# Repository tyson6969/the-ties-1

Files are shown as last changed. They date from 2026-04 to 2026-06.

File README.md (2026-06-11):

# The Ties

A **9 key 3 encoder macropad** running on QMK firmware and a **RP2040 MCU**

**Features:**
- 3D printed shell
- Custom PCB
- LEDs
- All running on QMK firmware
- Change buttons, shortcuts, and LEDs from your browser on QMK
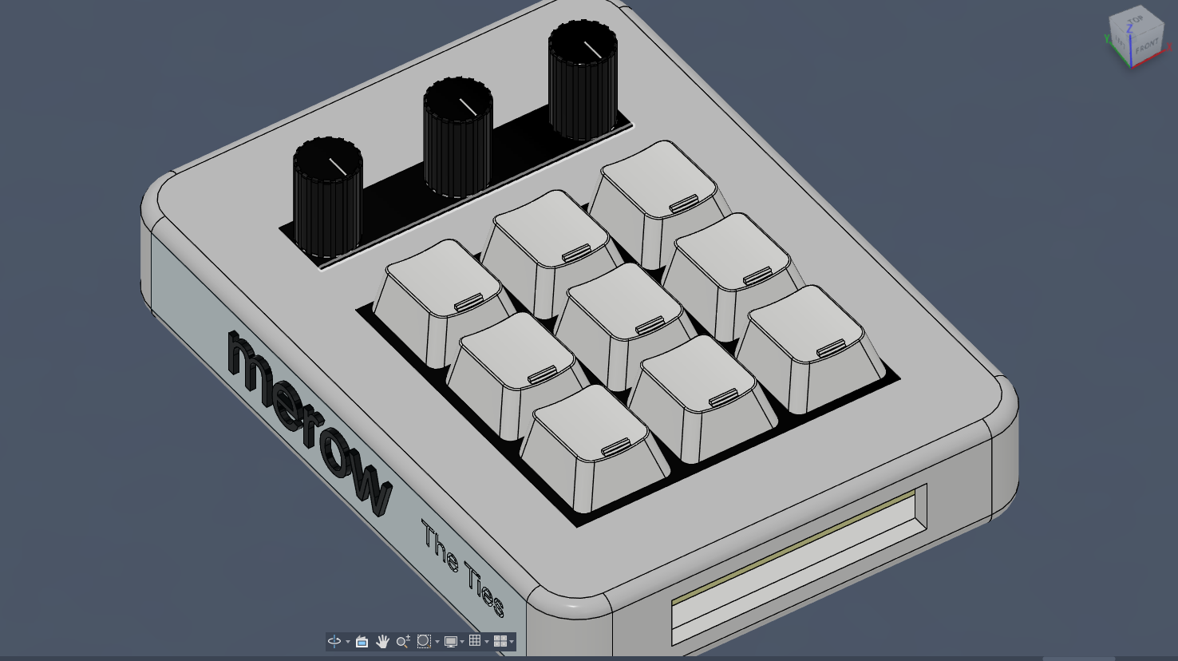
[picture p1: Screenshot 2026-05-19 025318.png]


## PCBA DESIGN

**A 4 layer board**

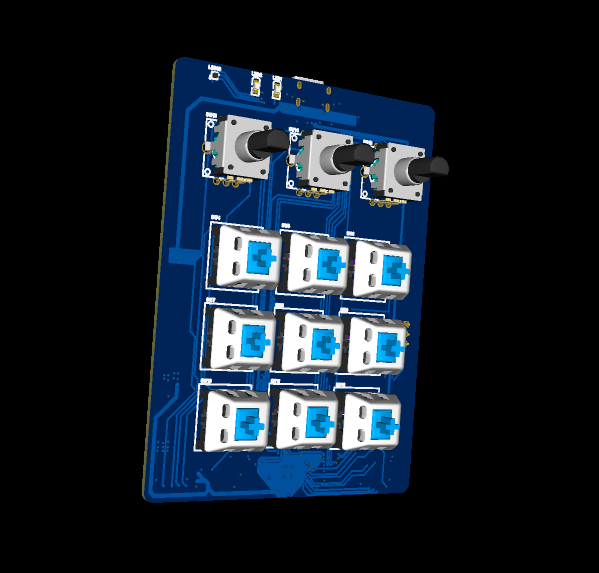
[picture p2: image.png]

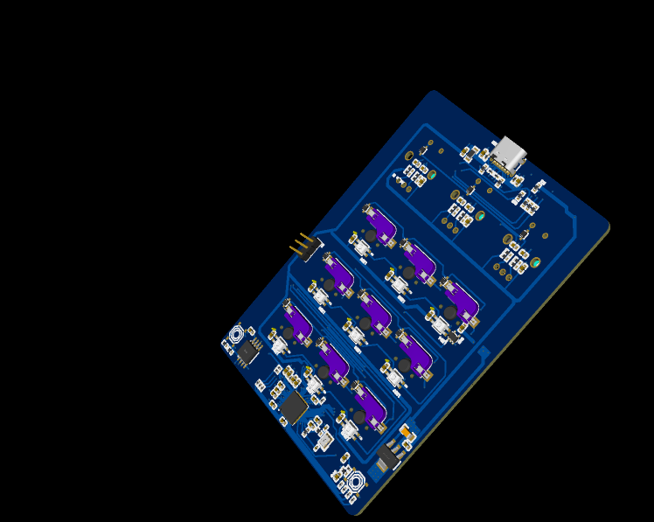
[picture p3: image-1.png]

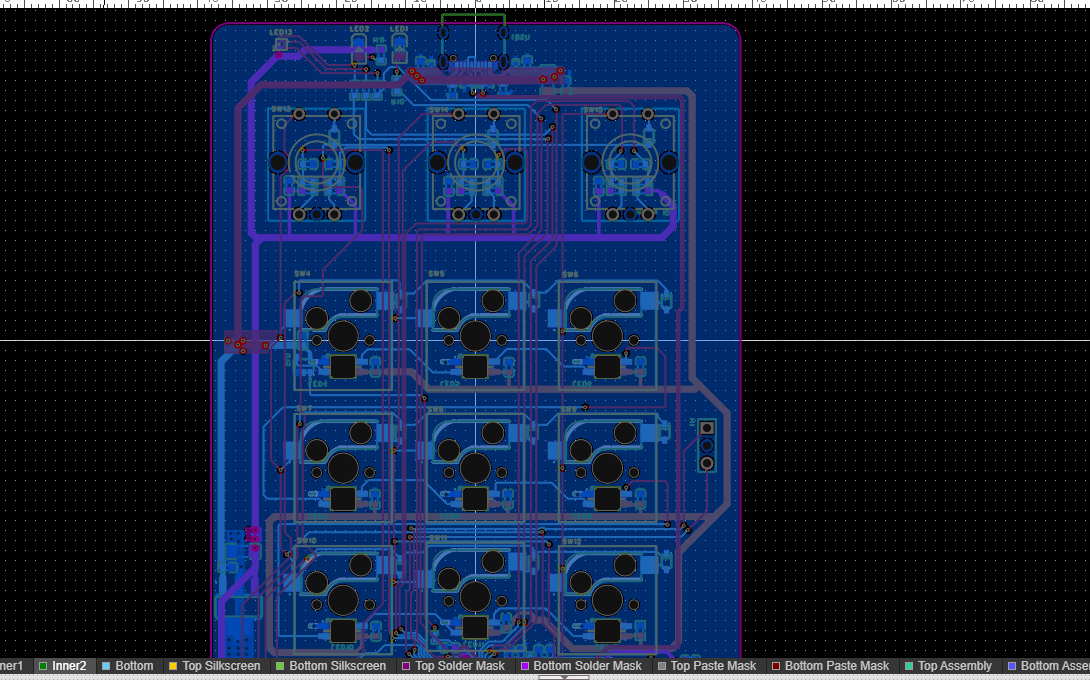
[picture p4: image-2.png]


Built on the **RP2040**  integrated directly into the board with all the typical components you will see on a RP2040 dev board.

**Schematics:**

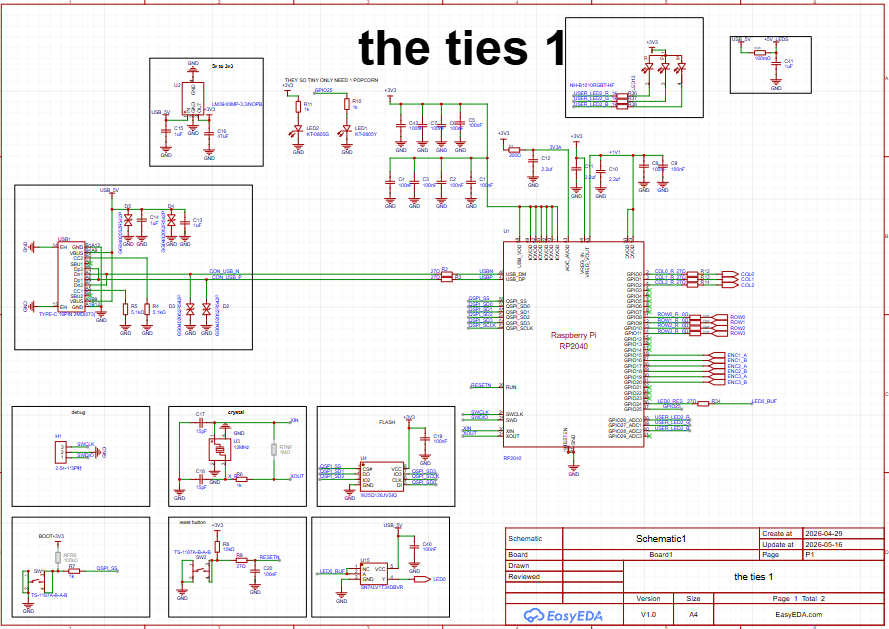
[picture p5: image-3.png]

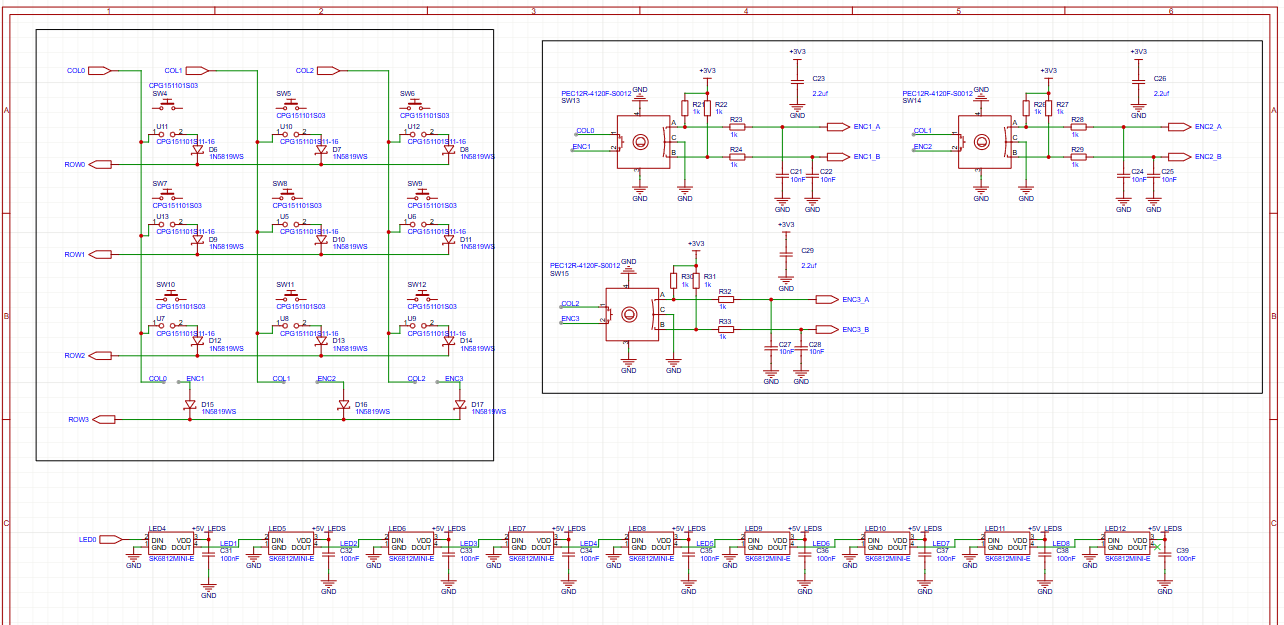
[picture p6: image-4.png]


## Case Design



Fully 3D printed

## Firmware

**Credits:**

This firmware is based on open source code by Robert Feranec
https://www.youtube.com/@RobertFeranec. 
i forked it with minimal modifications, but all the original code is from them.
It runs on **QMK firmware**, which is also open source.

## Files

### BOM
[BOM](https://github.com/tyson6969/the-ties-1/blob/main/BOM_Board1_Schematic1_2026-05-19.xlsx)

### Gerber Files
[Gerber Files](https://github.com/tyson6969/the-ties-1/blob/main/thetiesgerber.zip)

### 3D Printed Case
[3D Model](https://github.com/tyson6969/the-ties-1/blob/main/the%20ties%20CASE.stl)

### Software
[Software](https://github.com/tyson6969/the-ties-1/tree/main/Software)

### f3d files
[3D file ](https://github.com/tyson6969/the-ties-1/blob/main/the%20ties.f3z)

### ebro files
[3D file ](https://github.com/tyson6969/the-ties-1/blob/main/the%20ties%20.epro) this for mr cyao 

## Demo

https://youtu.be/uFGrd8xYUWo

# NO AI WAS USED IN THIS PROJECT

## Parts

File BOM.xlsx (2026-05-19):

No. | Quantity | Comment | Designator | Footprint | Value | Manufacturer Part | Manufacturer | Supplier Part | Supplier
1 | 22 | 100nF | C1,C2,C3,C4,C5,C6,C7,C8,C9,C19,C20,C31,C32,C33,C34,C35,C36,C37,C38,C39,C40,C42 | C0603 | 100nF
2 | 6 | 2.2uf | C10,C11,C12,C23,C26,C29 | C0603 | 2.2uf
3 | 4 | 1uF | C13,C14,C15,C41 | C0603 | 1uF
4 | 1 | 47uF | C16 | C1206 | 47uF | CL31A476MPHNNNE | SAMSUNG(三星) | C96123 | LCSC
5 | 2 | 15pF | C17,C18 | C0402 | 15pF | CL05C150JB5NNNC | SAMSUNG(三星) | C86285 | LCSC
6 | 6 | 10nF | C21,C22,C24,C25,C27,C28 | C0603 | 10nF
7 | 4 | GG0402052R542P | D2,D3,D4,D5 | D0402-BI |  | GG0402052R542P | Kyocera AVX | C1973257 | LCSC
8 | 12 | 1N5819WS | D6,D7,D8,D9,D10,D11,D12,D13,D14,D15,D16,D17 | SOD-323_L1.8-W1.3-LS2.5-RD |  | 1N5819WS | Hottech(合科泰) | C191023 | LCSC
9 | 1 | 2.54-1*3P针 | H1 | HDR-TH_3P-P2.54-V-M-1 |  | 2.54-1*3P针 | BOOMELE(博穆精密) | C49257 | LCSC
10 | 1 | KT-0805Y | LED1 | LED0805-R-RD |  | KT-0805Y | KENTO | C2296 | LCSC
11 | 1 | KT-0805G | LED2 | LED0805-R-RD |  | KT-0805G | KENTO | C2297 | LCSC
12 | 9 | SK6812MINI-E | LED4,LED5,LED6,LED7,LED8,LED9,LED10,LED11,LED12 | LED-SMD_4P-L3.2-W2.8-LS5.9_SK6812MINI-E |  | SK6812MINI-E | 欧思科光电 | C5149201 | LCSC
13 | 1 | NH-B1010RGBT-HF | LED13 | LED-ARRAY-SMD_4P-L1.0-W1.0-TR_NH-B1010RGBT |  | NH-B1010RGBT-HF | 国星光电 | C2874113 | LCSC
14 | 1 | 200Ω | R1 | R0402 | 200Ω | 0402WGF2000TCE | UNI-ROYAL(厚声) | C25087 | LCSC
15 | 7 | 27Ω | R2,R3,R9,R12,R13,R14,R34 | R0402 | 27Ω | 0402WGF270JTCE | UNI-ROYAL(厚声) | C25100 | LCSC
16 | 2 | 5.1kΩ | R4,R5 | R0603 | 5.1kΩ
17 | 19 | 1k | R6,R7,R10,R11,R21,R22,R23,R24,R26,R27,R28,R29,R30,R31,R32,R33,R36,R37,R38 | R0603 | 1k
18 | 1 | 10kΩ | R8 | R0603 | 10kΩ
19 | 4 | 0Ω | R18,R19,R20,R25 | R0402 | 0Ω | 0402WGF0000TCE | UNI-ROYAL(厚声) | C17168 | LCSC
20 | 1 | 100mΩ | R35 | R1206 | 100mΩ | 1206W4F100LT5E | UNI-ROYAL(厚声) | C25334 | LCSC
21 | 2 | TS-1187A-B-A-B | SW1,SW2 | SW-SMD_4P-L5.1-W5.1-P3.70-LS6.5-TL_H1.5 |  | TS-1187A-B-A-B | XKB Connection(中国星坤) | C318884 | LCSC
22 | 9 | CPG151101S03 | SW4,SW5,SW6,SW7,SW8,SW9,SW10,SW11,SW12 | KEY-TH_CPG1511F01S0X |  | CPG151101S03 | Kailh(凯华) | C404350 | LCSC
23 | 3 | PEC12R-4120F-S0012 | SW13,SW14,SW15 | SW-TH_PEC12R-4120F-S0012 |  | PEC12R-4120F-S0012 | BOURNS | C143801 | LCSC
24 | 1 | RP2040 | U1 | LQFN-56_L7.0-W7.0-P0.4-EP |  | RP2040 | Raspberry Pi(树莓派) | C2040 | LCSC
25 | 1 | LM3940IMP-3.3/NOPB | U2 | SOT-223_L6.5-W3.5-P2.30-LS7.0-BR |  | LM3940IMP-3.3/NOPB | TI(德州仪器) | C140319 | LCSC
26 | 1 | 12MHz | U3 | CRYSTAL-SMD_4P-L3.2-W2.5-BL | 12MHz | ABM8-272-T3 | ABRACON | C20625731 | LCSC
27 | 1 | W25Q128JVSIQ | U4 | SOIC-8_L5.3-W5.3-P1.27-LS8.0-BL |  | W25Q128JVSIQ | Winbond(华邦) | C97521 | LCSC
28 | 9 | CPG151101S11-16 | U5,U6,U7,U8,U9,U10,U11,U12,U13 | SMD_KEYBOARD-SW |  | CPG151101S11-16 | Kailh(凯华) | C5156480 | LCSC
29 | 1 | SN74LV1T34DBVR | U15 | SOT-23-5_L2.9-W1.6-P0.95-LS2.8-BR |  | SN74LV1T34DBVR | TI(德州仪器) | C100024 | LCSC
30 | 1 | TYPE-C 16PIN 2MD(073) | USB1 | USB-C-SMD_TYPE-C-16PIN-2MD-073 |  | TYPE-C 16PIN 2MD(073) | SHOU HAN(首韩) | C2765186 | LCSC

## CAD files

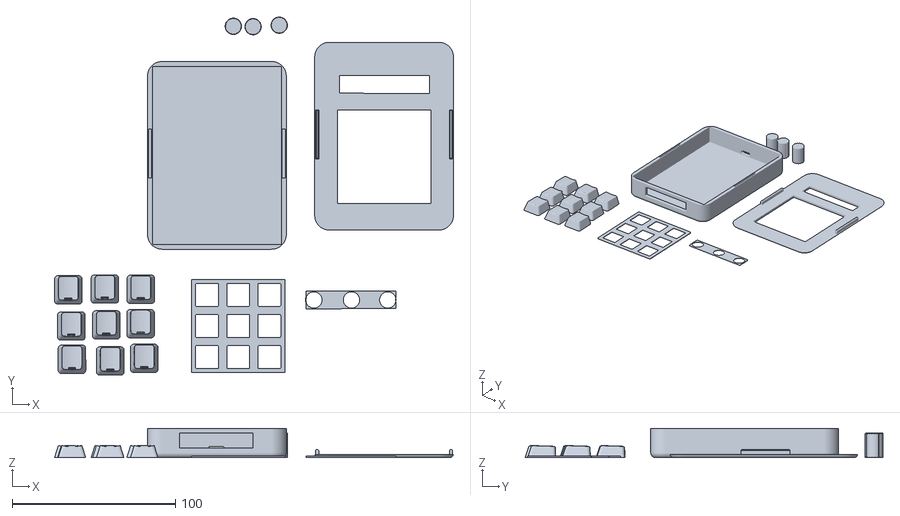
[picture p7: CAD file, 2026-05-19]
the ties CASE.stl
244.3 x 219.3 x 18.0

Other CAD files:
the ties.f3z

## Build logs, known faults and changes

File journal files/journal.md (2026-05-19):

sorry for the spelling mistakes i make 

day 1 the start 4/29/2026
time tracked - 1.30h

soooooooooooo firstly it was honestly annoying bro omg i wanted to make a macropad so i decided sure lemme make one how hard could it be i only used easyeda before and i dont feel like learning kicad so i just rolled with it i first had to see the qmk docs to know what i was dealing with then i chose a mcu i decided to go with the pico cus its easy yk lots of docs then i opened the docs for it went to the wiring diagram and hell began
i placed the chip in easyeda and i edited the footprint to make it look a lil nice easy to work with ik i am a dumbahh

so i started by adding all the capacitors linking them to gnd and honestly idk what was i doing i kept looking between the docs and drc to figure out what to do i added caps to the VODD pins all of em then i decided to add the usb c which gave me lots of trouble dude i first started routing it with my skills learnt from the usb hub hehehehe i connected them to the usb of the pico i added a shield but when i saw it it felt it looked ugly asf so i deleted everything and tried making it look pretty but i felt like it wont work so i had to redo everything again pain and now the usb c is done i think here is the schematics so far 
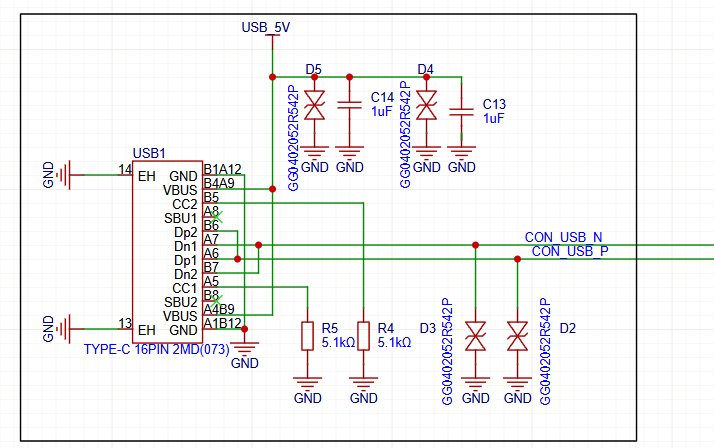
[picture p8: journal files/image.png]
looks so messy ik ik ! okay my dumbahh lost the pic sorry but here is the final usb c i think 

day 2 finished the mcu schematics 4/29/2026
time tracked - 1h

yippe i finished it i added a lot of things firstly the 
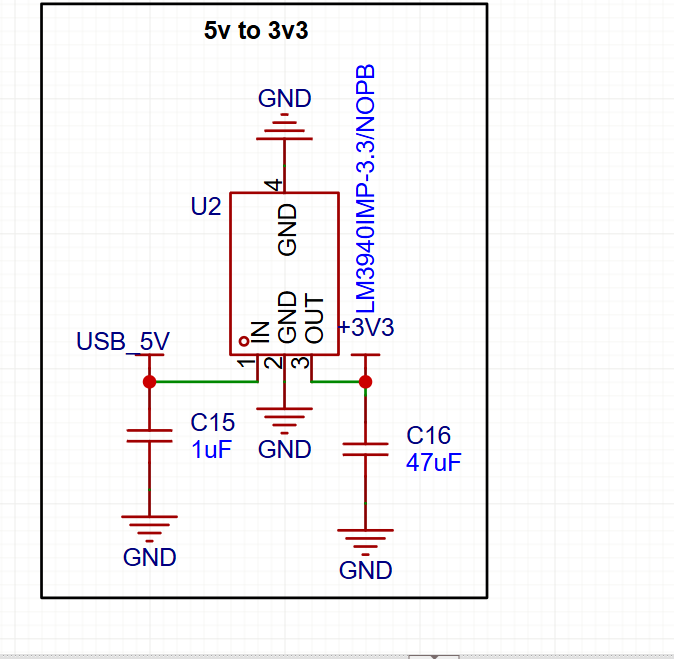
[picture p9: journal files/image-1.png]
voltage regulator 

crystal
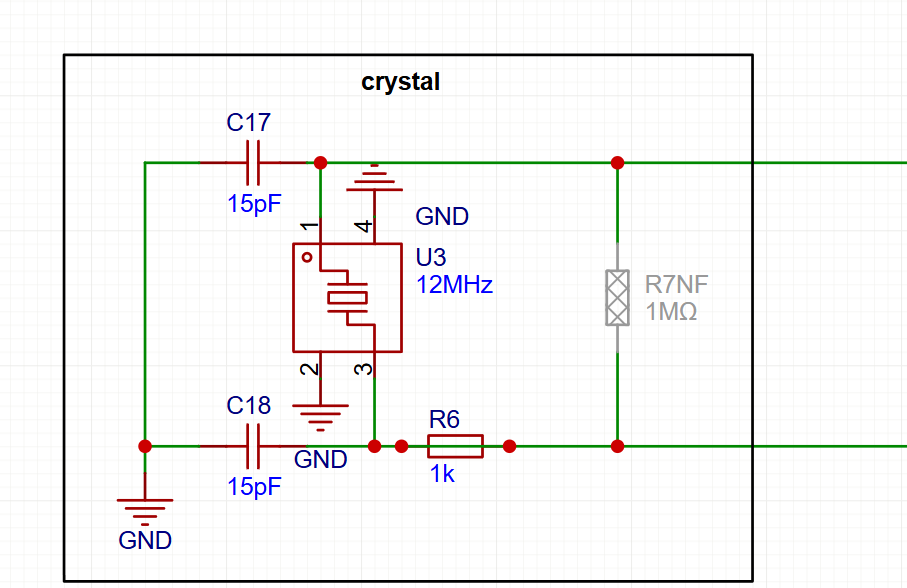
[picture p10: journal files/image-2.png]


debug for debugging duh
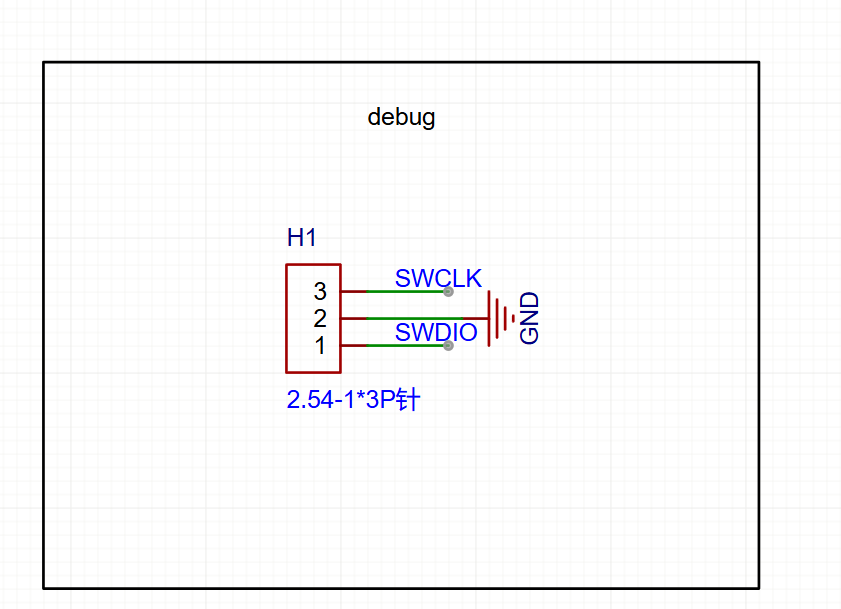
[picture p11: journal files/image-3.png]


boot switch for switching duhh
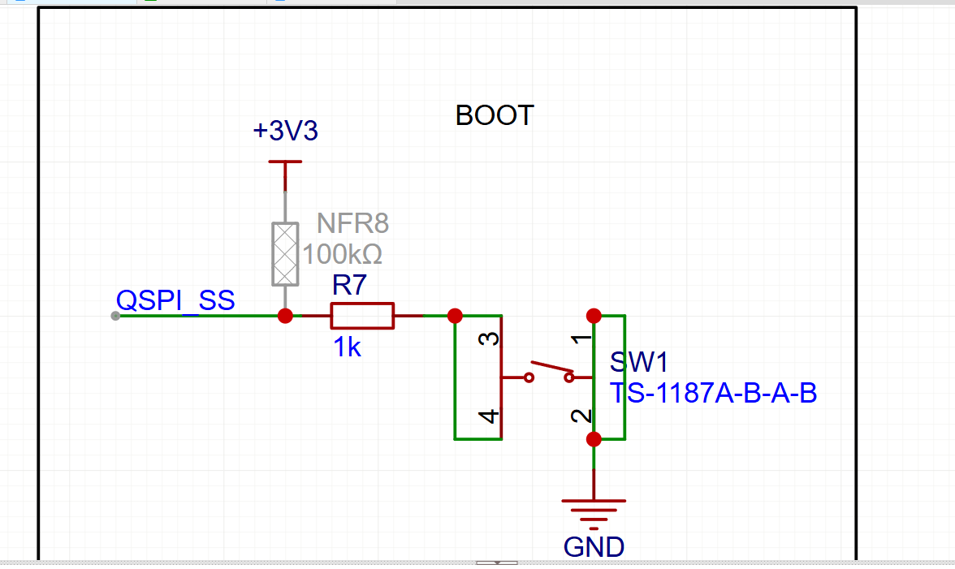
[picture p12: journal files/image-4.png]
 

 reset button for resetting duhhh 
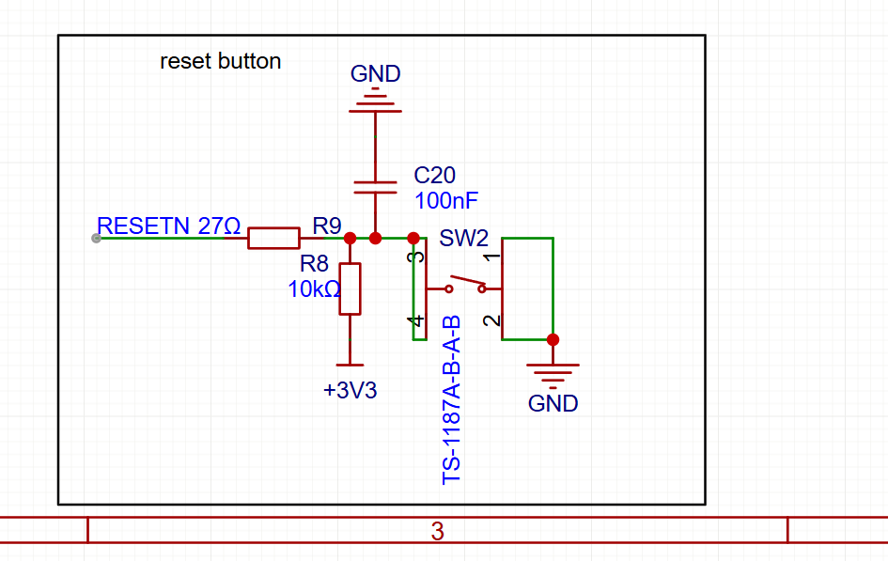
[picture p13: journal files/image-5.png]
 

 flash for what say it with me for flashing duhhhhh
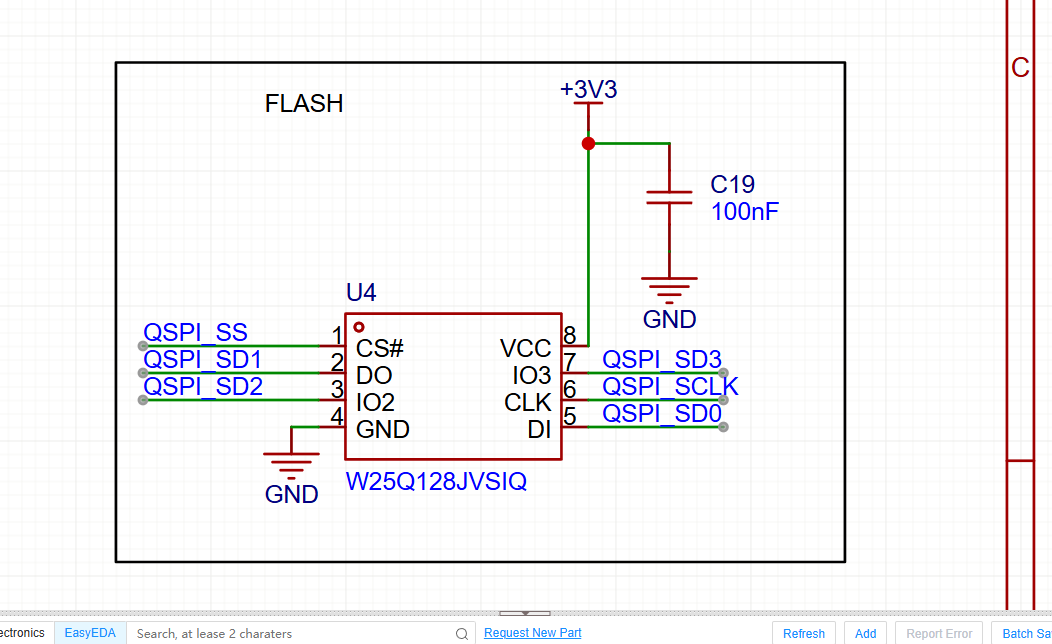
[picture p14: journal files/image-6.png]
  

  then those lil baby cute leds 
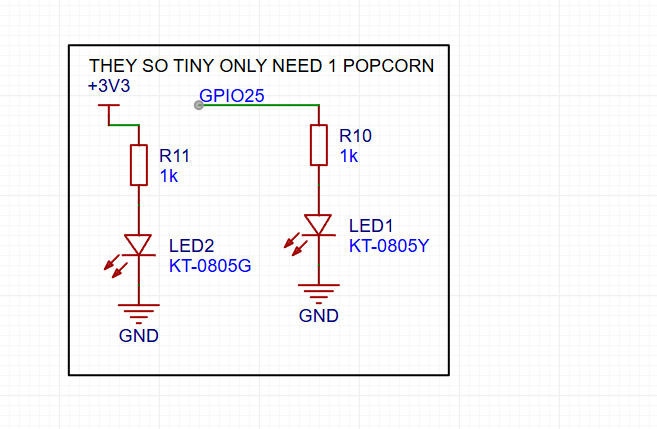
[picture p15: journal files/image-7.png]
  

i just saw the docs kept following it not really much trouble and now were done yay 

day 3 started working on the switches 5/9/2026
time tracked - 1.3

okay so i decided to finally get back to this 
i first started by get a switch shaft then i edited the footprint cus it was lowk pmo and made it looks better i kinda failed

then i also got my switch and edited the footprint it still pmo so i edited the footprint much more
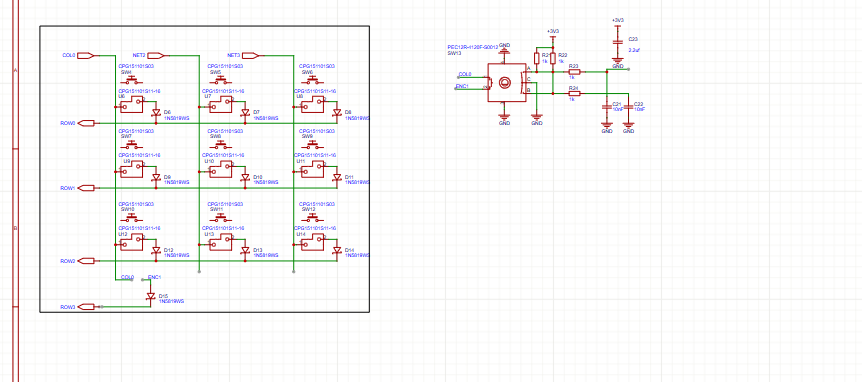
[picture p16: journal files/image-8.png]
then i connected it to some capacitors and made the rows and columns then i connected it to the mcu and then i got a rotary encoder and did the same changed the footprint and connected it 

day 4 YAYAYAY I FINISHED THE SCHEMATICS 5/9/2026
time tracked - 1.3
what mostly i did was just add leds i finished the encoders and wired them up
i also finished the leds
i also added an rgb led for feedback so i started changing the footprint cus it was very ugly and me gag tbh but i made it look cool i am so awesome  and i finished wiring everything putting it together and here the final schematics 
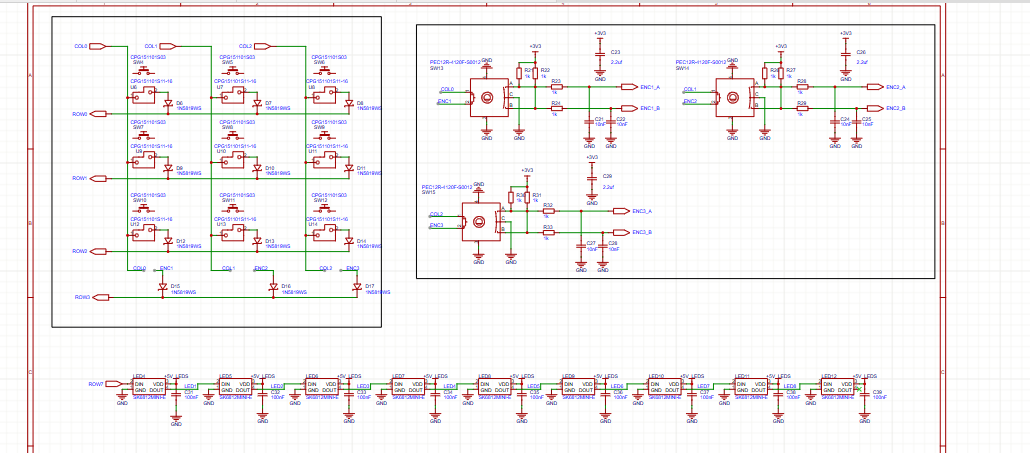
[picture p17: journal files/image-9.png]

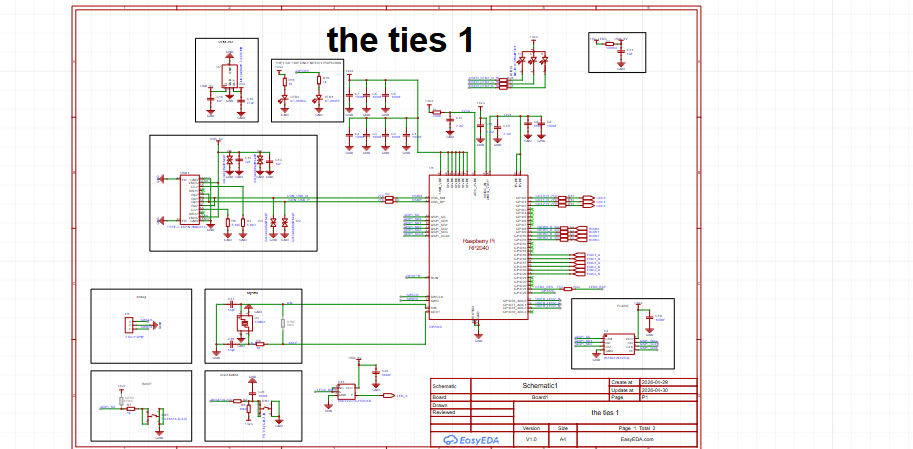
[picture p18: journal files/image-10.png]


day 5 and 6
time tracked = 2h
hello there dear reviewer
sososoos i did a lot of things well not a lot kinda one but like kinda a lot at the same time after i finished the schematics it was time for the great pcb so the first part was like 2 days ago and i was super sick and tired so i might not remember what i did but all i remember is me making the pcb outline adding the switches and the switch caps i think and there was a problem with the switch caps so i had to redo the footprint all over again and then i placed the board and wired the caps for it 
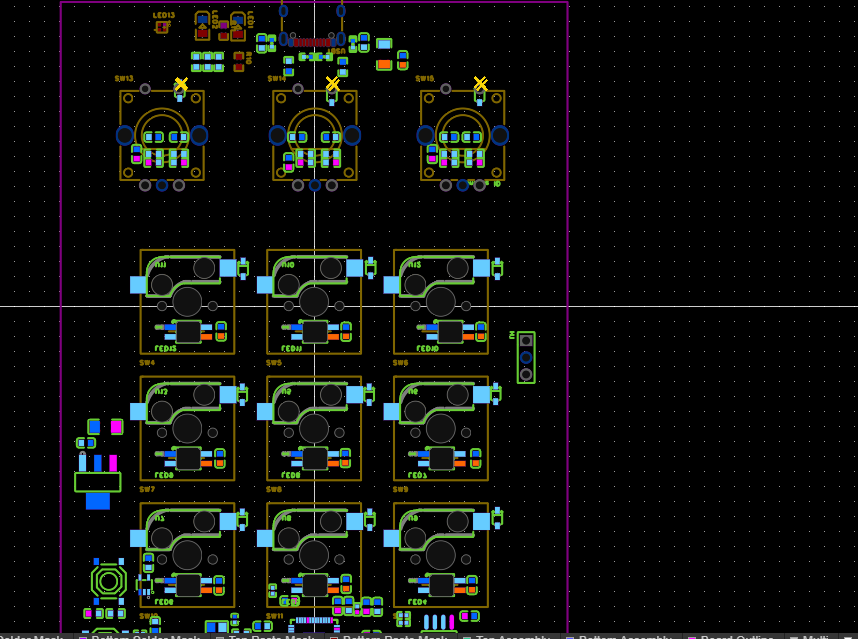
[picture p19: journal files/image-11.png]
and part 2 is where i finished it not a lot happened just placing the parts going back and forth i also made the schematics look a bit nicer and i noticed an issue with the switches that the 3d model was off so i had to re do all the switches but i finally got it and now its finished looks pretty 

day 7
time tracked 2.6h 

started the pain of the routing so this is the hardest part routing so i had really really small place to work with 
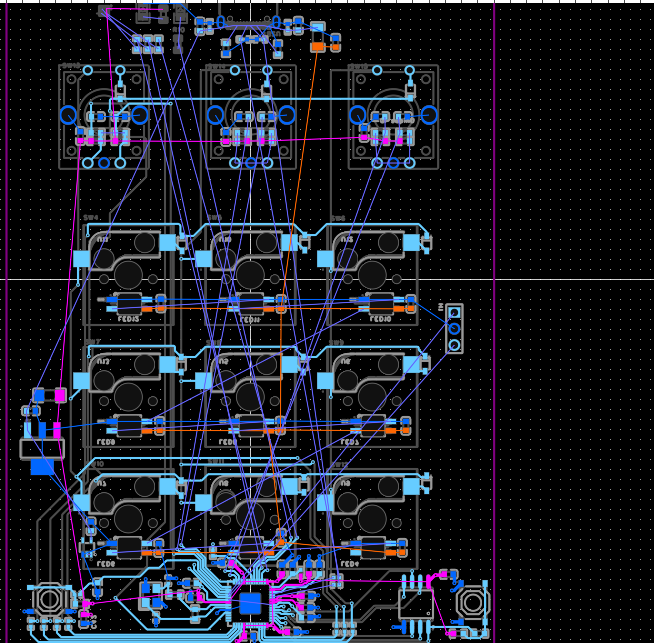
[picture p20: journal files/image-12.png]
but before routing i had to add some design rules so i did that changed everything and changed the vias to be easy and cheap for manufacturing and after i did that for some reason it said the lines r too thick so i had to redo all the design rules and restore them to default but for also some unknown reason it still said i cant until i discovered i need to change the width of the connection and re did all my design rules so after that i started the poor old routing which is not much but i had tooo little space so i was struggling so much u dont even know but i managed then i had the worst thing possible the flash pins there was so little space so i just sat there for like what half an hour trying to wiggle it and creating as much space as possible for vias to go on the top layer and i finally did it so after that i went to connect the rows and cols of switches was pretty easy and then i got to routing the encoders i got pretty bored tbh so i just did 1 and said done for the day so prolly gonna continue later 
here is progress 

day 8
time tracked: 3:53h
 sorry for not journaling as much i was pretty tired

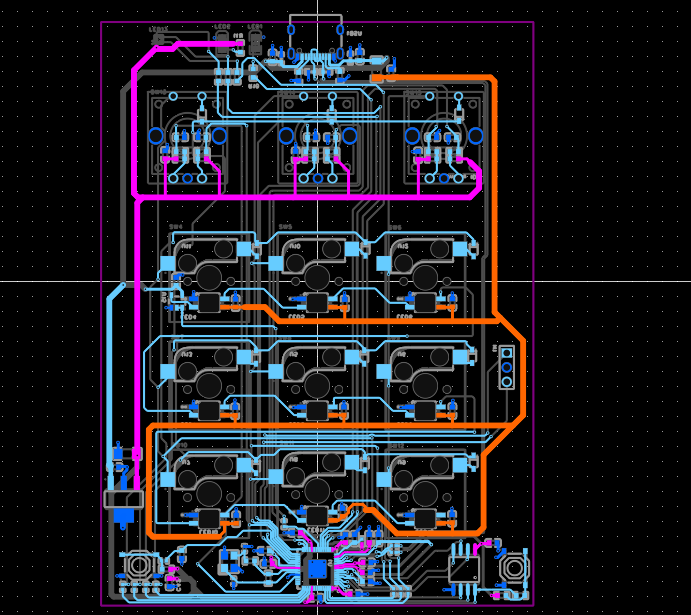
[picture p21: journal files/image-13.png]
holy moly ok so i dont remember everything that happened cus it was multiple sessions  but basically i think i started with the encoders and it was also very tricky cus i had to take them up from the bottom and then route them all the way up i am pretty tired cus its so annoying to like route and get all of these connections out of the way but we made it then i also connected the user led which was the hardest cus the pins were buried deep under the led was up on the board so i had to do a lot of go around until i finally connected then i started with the usb DP connections and had to route them all the way under and ofc i had to wiggle everything to make space for it ugh then session 2 where i think i started with the leds but at first i thought there was something weird but idk then after connecting all of them i realized idk where the buffer is so i went to change the buffer for the leds and then panic started i realized i had all the leds backwards so i had to relocate each switch and re route the pins,,, smh pain pain but i did it and i went to route the debug header and after that i added power for all the leds and routed them in rows so it can take power and i routed the power then i went to route the 5v usb yaya to the voltage regulator to get a 3v3 output to connect the encoders and speaking of encoders i discovered my dumbahh had the caps flipped so i had to re flip them and re route them i have must been really tired when i routed them back then also i discovered i had an issue with the encoder schematics so i edited that too and then i i i routed all the rest of the 3v3 power to the bottom and then the 1v1 which was very annoying cus i basically had 0 room but i finally made it and after that i routed all of the gnd pins rebuild the inner layers and finally YAYAYAYAY WE FINISHED yippe finished all the routing every trace with my heart  now bye dear reviewer 

day 9 
time tracked = 20 mins didnt do much just filled some copper regions made it look better added a lot of extra vias and its done
the pcb is done finally after 18 hrs of brutal brutal misery i did it i finished the pcb yuayayayayyaya im so happy okay now onto the the cad which is easy cus i love cad thx to construct

i am not done with it tho i am gonna improve the silk screen much more and gonna make it look cleaner just give me time cus i am tired of the easyeda menu

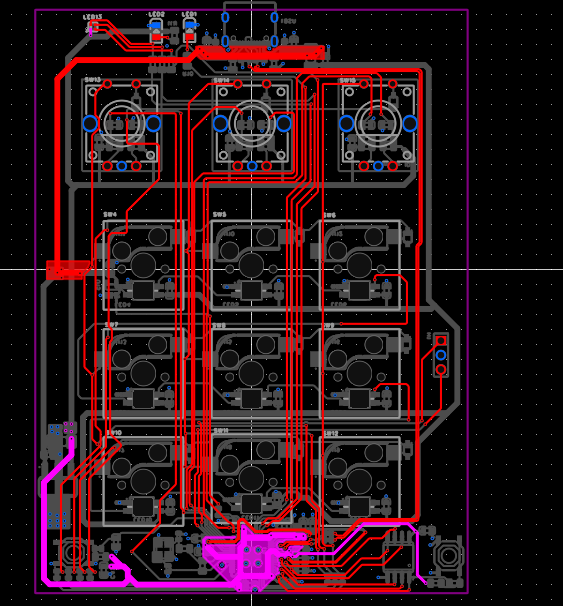
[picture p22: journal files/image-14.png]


day 10
time tracked 1.20h
okay so i started with the case design and i first went to easy eda to get the step files but after i did that for some reason most of the 3d models of some part wont load so smart me went to see why and then idk i played a lot and i ended up binding those part to a random 3dmodel so i had to go back remove the 3d models and re bind them to the correct one im so done but i finally got the step to work got it into cad and we need to start working so i just slept and went to start tmrw okay it wasnt  much i just made a simple box tried to make a cool pattern but failed got the switch cut outs from a kle data thing then made a knob for the encoder and thats it gonna make the case look much better tho
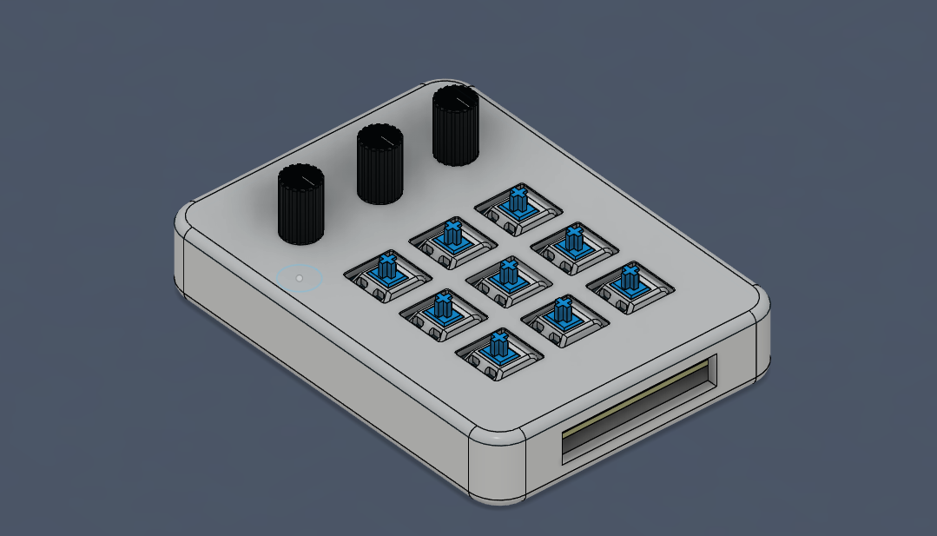
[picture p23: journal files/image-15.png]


day 11 
time tracked 30 mins
okay sooo i made plate for the keyboard so it hides the ugly lookin switches also the same for encoders i made the case look prettier i added a meow text although removed it then  it came to switches i had a pre designed switch so i just added it edited a lil so its like a lil shorter and its done i took a photo then got the part popped them into bambu studio but lapse for some reason didnt change the screen pain but i got it all setup and here is how it looks  okay its now software time but since i asked in horizon help if i can use open source code im just gonna add code i know is gonna work because it has same mcu and same layout of rows and

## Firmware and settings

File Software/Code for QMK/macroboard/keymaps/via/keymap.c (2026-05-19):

#include QMK_KEYBOARD_H

enum layer_names {
    _BASE
};

const uint16_t PROGMEM keymaps[][MATRIX_ROWS][MATRIX_COLS] = {
    [_BASE] = LAYOUT_mp10(
        QK_USER_0   , KC_A   ,  KC_A  ,
        KC_A   , KC_A   , KC_A   ,
        KC_A   , KC_A   , KC_A   ,
        KC_A   , KC_A   , KC_A  
    )
};

#if defined(ENCODER_MAP_ENABLE)
const uint16_t PROGMEM encoder_map[][NUM_ENCODERS][NUM_DIRECTIONS] = {
    [_BASE] =   { ENCODER_CCW_CW(KC_LEFT, KC_RIGHT), ENCODER_CCW_CW(KC_LEFT, KC_RIGHT), ENCODER_CCW_CW(KC_LEFT, KC_RIGHT) }
};
#endif

void keyboard_pre_init_user(void) {
  setPinOutput(GP26);
  setPinOutput(GP27);
  setPinOutput(GP28);
}

void keyboard_post_init_user(void) {
  writePinHigh(GP26);
  writePinHigh(GP27);
  writePinHigh(GP28);
}

enum custom_keycodes {
  LAYER_SCROLL = QK_USER_0
};

bool process_record_user(uint16_t keycode, keyrecord_t *record) {
  switch (keycode) {
    case LAYER_SCROLL:
      if (!record->event.pressed) {
        //Already handled the keycode, no further processing is needed
        return false;
      }

      uint8_t current_layer = get_highest_layer(layer_state);
      if (current_layer > 3 || current_layer < 0) {
        return false;
      }

      uint8_t next_layer = current_layer + 1;
      if (next_layer > 3) {
        next_layer = 0;
      }

      if (next_layer == 0) {
        writePinHigh(GP26);
        writePinHigh(GP27);
        writePinHigh(GP28);
      }
      if (next_layer == 1) {
        writePinLow(GP26);
        writePinHigh(GP27);
        writePinHigh(GP28);
      }
      if (next_layer == 2) {
        writePinHigh(GP26);
        writePinLow(GP27);
        writePinHigh(GP28);
      }
      if (next_layer == 3) {
        writePinHigh(GP26);
        writePinHigh(GP27);
        writePinLow(GP28);
      }

      layer_move(next_layer);
      
      return false;
    default:
      return true; //Process all other keycodes normally
  }
}

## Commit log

2026-05-17 finished the cad model
2026-05-18 finished case
2026-05-19 read me update
    [BOM_Board1_Schematic1_2026-05-19.xlsx, the ties CASE.stl]
2026-05-23 bom name edit
    [BOM.xlsx]
2026-06-11 added f3d
    [the ties.f3z]
